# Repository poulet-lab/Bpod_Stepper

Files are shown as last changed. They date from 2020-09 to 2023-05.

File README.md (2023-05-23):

# Bpod Stepper Module

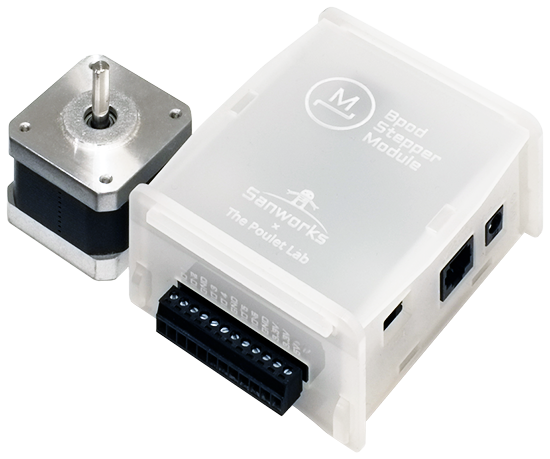
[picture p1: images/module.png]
The *Bpod Stepper Module* enables virtually noiseless operation of a stepper motor by combining smooth acceleration profiles with a *SilentStepStick* driver. You can use it either as a module for *Bpod state machine r2* or as a stand-alone USB device.

## Wiki

Please refer to [**the wiki**](../../wiki) for documentation.

## Credits ##

* Concept & firmware by Florian Rau and Josh Sanders
* PCB layout by Christopher Schultz, Josh Sanders and Florian Rau
* PCB layout partially based on:
  * [Bpod Teensy Shield](https://github.com/sanworks/Bpod-CAD/tree/master/PCB/Modules/Gen2/Bpod%20Teensy%20Shield) by Sanworks ([GPL v3](https://www.gnu.org/licenses/gpl-3.0.en.html))
  * [SilentStepStick Protector](https://github.com/watterott/SilentStepStick) by Watterott ([CC BY-SA 4.0](https://creativecommons.org/licenses/by-sa/4.0/))
* Library dependencies:
  * [ArCOM](https://github.com/bimac/ArCOM) by Sanworks ([GPL v3](https://www.gnu.org/licenses/gpl-3.0.en.html))
  * [TeensyStep](https://github.com/luni64/TeensyStep) by luni64 ([MIT](https://opensource.org/licenses/MIT))
  * [TMCStepper](https://github.com/teemuatlut/TMCStepper) by teemuatlut ([MIT](https://opensource.org/licenses/MIT))
  * [Teensy3x_QuadDecode](https://github.com/bimac/Teensy3x_QuadDecode.git) by TLB ([MIT](https://opensource.org/licenses/MIT))

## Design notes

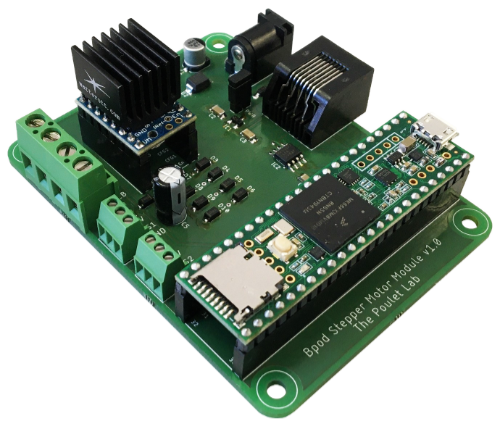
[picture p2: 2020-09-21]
images/board.png

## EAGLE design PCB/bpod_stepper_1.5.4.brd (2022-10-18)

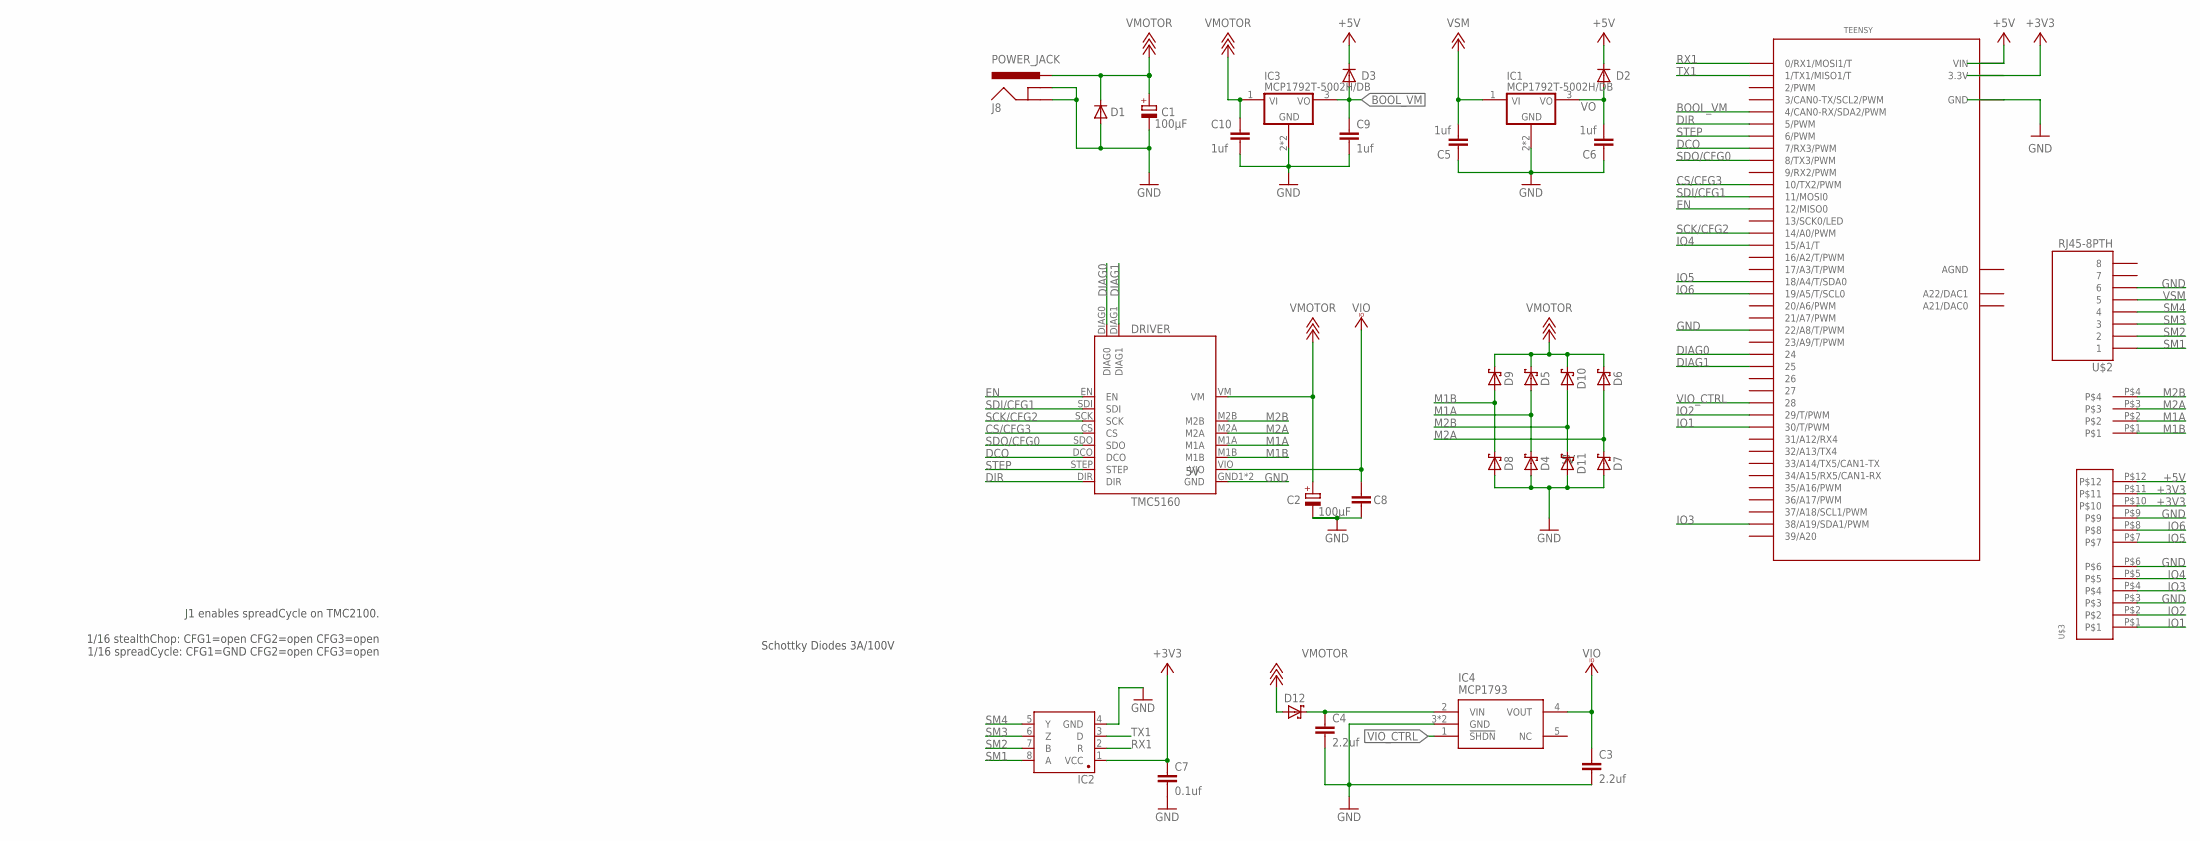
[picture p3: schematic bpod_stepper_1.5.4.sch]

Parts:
C1, C2: 100µF; PANASONIC_G
C3, C4: 2.2uf; 1206@1
C5, C6, C9, C10: 1uf; 1206@1
C7: 0.1uf; 1206@1
C8: 100nf; 1206@1
D1: DIODE-DO214AA; DO214AA
D2, D3: MBR0520LT; SOD123
D4, D5, D6, D7, D8, D9, D10, D11, D12: S310FA; SOD123
DRIVER: TMC5160
IC1, IC3: MCP1792T-5002H/DB; SOT223
IC2: SN65HVD31DR; SO08
IC4: MCP1793; SOT223-5
J8: POWER_JACK; POWER_JACK_PTH
TEENSY: TEENSY_3.6_DIL
U$2: RJ45-8PTH; RJ45-8
U$3: 12POS_MOLEX_SOCKET
U$4: MOLEX395221004

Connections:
+3V3: C7.1, IC2.1 (VCC), TEENSY.3.3V, TEENSY.3.3V3 (3.3V), U$3.P$10, U$3.P$11
+5V: D2.C, D3.C, TEENSY.VIN, U$3.P$12
AGND: TEENSY.AGND
BOOL_VM: C9.1, D3.A, IC3.3 (VO), TEENSY.4 (4/CAN0-RX/SDA2/PWM)
CS/CFG3: DRIVER.CS, TEENSY.10 (10/TX2/PWM)
DCO: DRIVER.DCO, TEENSY.7 (7/RX3/PWM)
DIAG0: DRIVER.DIAG0, TEENSY.24
DIAG1: DRIVER.DIAG1, TEENSY.25
DIR: DRIVER.DIR, TEENSY.5 (5/PWM)
EN: DRIVER.EN, TEENSY.12 (12/MISO0)
GND: C1.-, C2.-, C3.2, C4.2, C5.1, C6.1, C7.2, C8.2, C9.2, C10.2, D1.A, D4.A, D7.A, D8.A, D11.A, DRIVER.GND1 (GND), DRIVER.GND2 (GND), IC1.2 (GND), IC1.4 (GND), IC2.4 (GND), IC3.2 (GND), IC3.4 (GND), IC4.3 (GND), IC4.6 (GND), J8.GND, J8.GNDBREAK, TEENSY.22/A8 (22/A8/T/PWM), TEENSY.GND, TEENSY.GND1 (GND), U$2.6, U$3.P$3, U$3.P$6, U$3.P$9
IO1: TEENSY.30 (30/T/PWM), U$3.P$1
IO2: TEENSY.29 (29/T/PWM), U$3.P$2
IO3: TEENSY.38/A19 (38/A19/SDA1/PWM), U$3.P$4
IO4: TEENSY.15/A1 (15/A1/T), U$3.P$5
IO5: TEENSY.18/A4 (18/A4/T/SDA0), U$3.P$7
IO6: TEENSY.19/A5 (19/A5/T/SCL0), U$3.P$8
M1A: D4.C, D5.A, DRIVER.M1A, U$4.P$2
M1B: D8.C, D9.A, DRIVER.M1B, U$4.P$1
M2A: D6.A, D7.C, DRIVER.M2A, U$4.P$3
M2B: D10.A, D11.C, DRIVER.M2B, U$4.P$4
unnamed: C4.1, D12.C, IC4.2 (VIN)
RX1: IC2.2 (R), TEENSY.0 (0/RX1/MOSI1/T)
SCK/CFG2: DRIVER.SCK, TEENSY.14/A0 (14/A0/PWM)
SDI/CFG1: DRIVER.SDI, TEENSY.11 (11/MOSI0)
SDO/CFG0: DRIVER.SDO, TEENSY.8 (8/TX3/PWM)
SM1: IC2.8 (A), U$2.1
SM2: IC2.7 (B), U$2.2
SM3: IC2.6 (Z), U$2.3
SM4: IC2.5 (Y), U$2.4
STEP: DRIVER.STEP, TEENSY.6 (6/PWM)
TX1: IC2.3 (D), TEENSY.1 (1/TX1/MISO1/T)
VIO: C3.1, C8.1, DRIVER.VIO, IC4.4 (VOUT)
VIO_CTRL: IC4.1 (!SHDN), TEENSY.28
VMOTOR: C1.+, C2.+, C10.1, D1.C, D5.C, D6.C, D9.C, D10.C, D12.A, DRIVER.VM, IC3.1 (VI), J8.PWR
VO: C6.2, D2.A, IC1.3 (VO)
VSM: C5.2, IC1.1 (VI), U$2.5

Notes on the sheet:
Schottky Diodes 3A/100V
J1 enables spreadCycle on TMC2100. 1/16 stealthChop: CFG1=open CFG2=open CFG3=open 1/16 spreadCycle: CFG1=GND CFG2=open CFG3=open

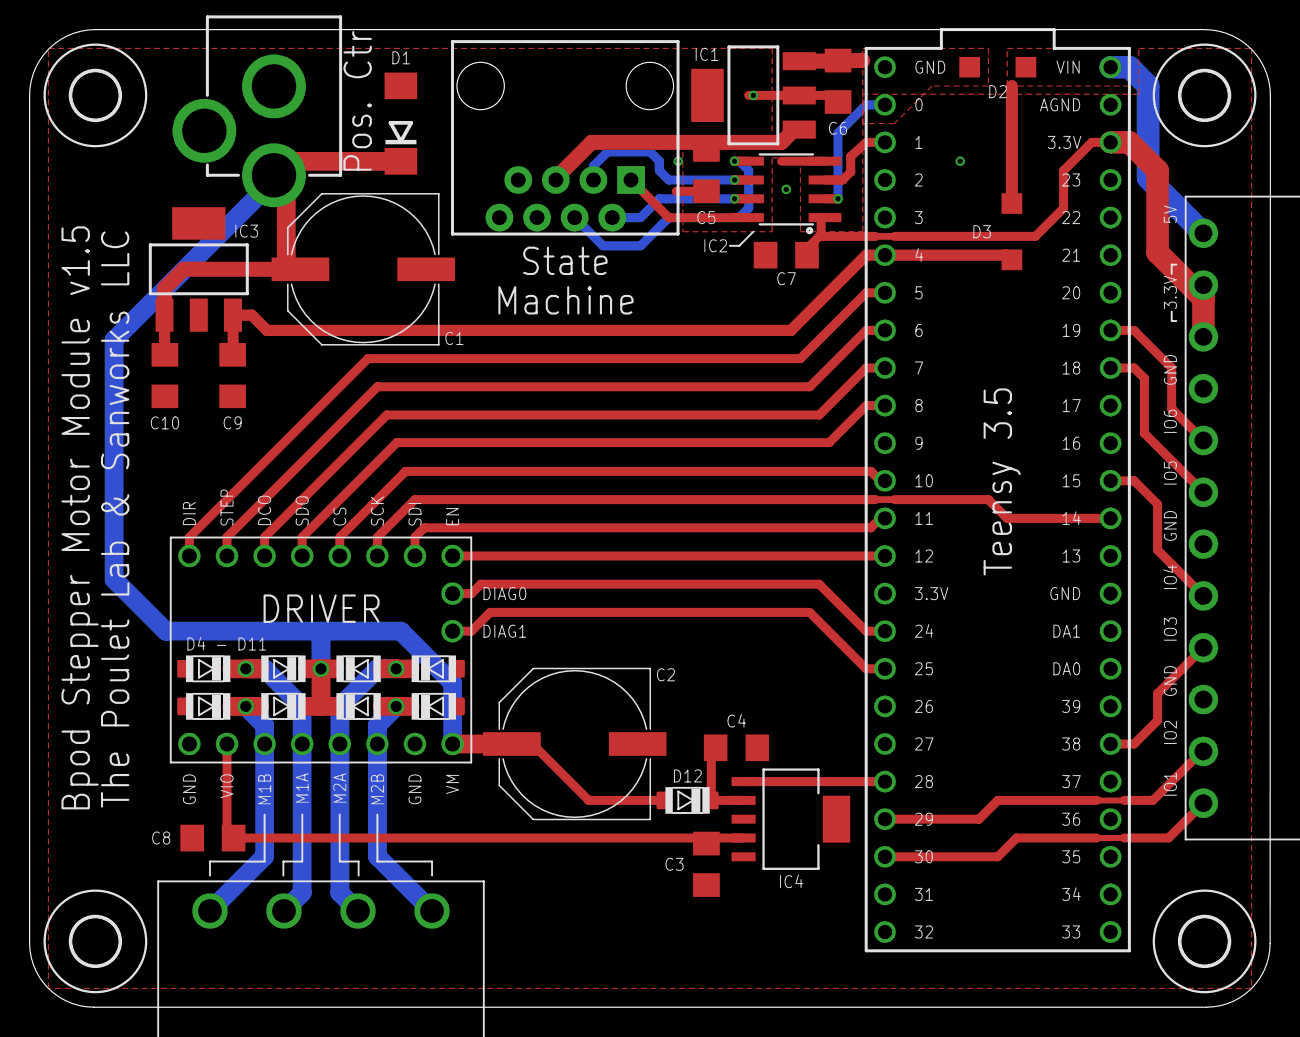
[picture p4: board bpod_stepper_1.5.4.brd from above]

Board: 2 copper layers, 83.8 x 66.0 mm, 36 parts (0 on the bottom side), 36 nets.

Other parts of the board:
U$7, U$8, U$9, U$10: 3,2

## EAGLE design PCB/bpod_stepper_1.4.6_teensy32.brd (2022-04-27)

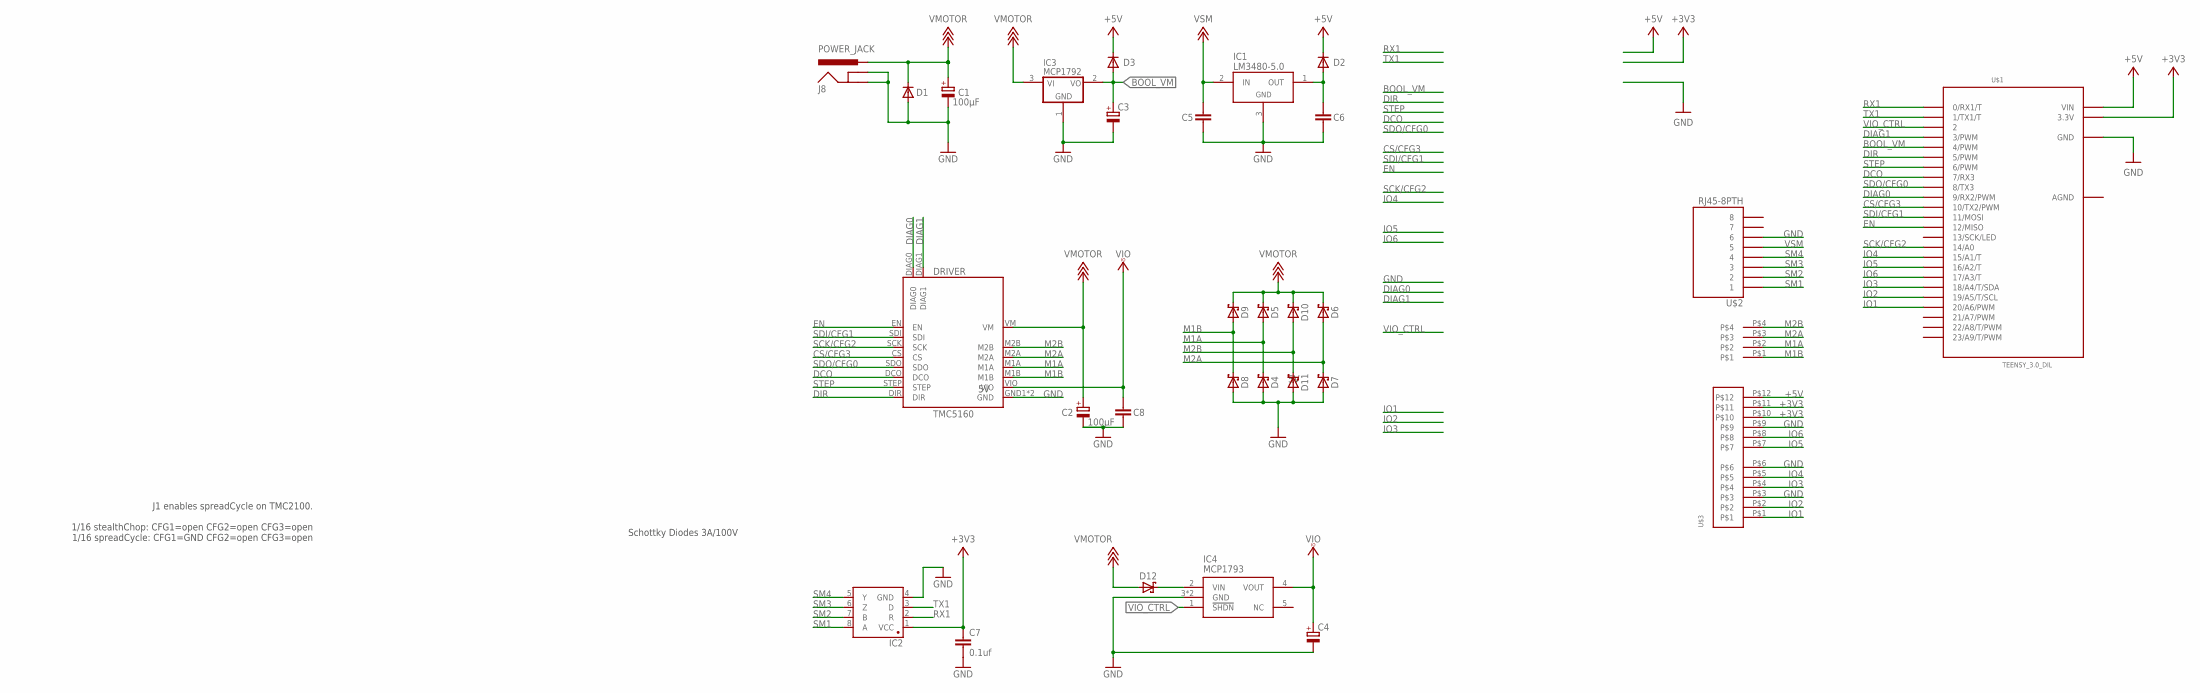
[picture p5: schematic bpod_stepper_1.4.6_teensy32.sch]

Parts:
C1, C2: 100µF; PANASONIC_G
C3, C4: CPOL-EUB; PANASONIC_B
C5, C6, C7: 0.1uf; 1206@1
C8: 100nf; 1206@1
D1: DIODE-DO214AA; DO214AA
D2, D3: MBR0520LT; SOD123
D4, D5, D6, D7, D8, D9, D10, D11, D12: S310FA; SOD123
DRIVER: TMC5160
IC1: LM3480-5.0; SOT-23-3
IC2: SN65HVD31DR; SO08
IC3: MCP1792; SOT23A_MICROCHIP_CB
IC4: MCP1793; SOT223-5
J8: POWER_JACK; POWER_JACK_PTH
U$1: TEENSY_3.0_DIL; TEENSY_3.0-3.2&LC_DIL
U$2: RJ45-8PTH; RJ45-8
U$3: 12POS_MOLEX_SOCKET
U$4: MOLEX395221004

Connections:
+3V3: C7.1, IC2.1 (VCC), U$1.3.3V, U$3.P$10, U$3.P$11
+5V: D2.C, D3.C, U$1.VIN, U$3.P$12
AGND: U$1.AGND
BOOL_VM: C3.+, D3.A, IC3.2 (VO), U$1.4 (4/PWM)
CS/CFG3: DRIVER.CS, U$1.10 (10/TX2/PWM)
DCO: DRIVER.DCO, U$1.7 (7/RX3)
DIAG0: DRIVER.DIAG0, U$1.9 (9/RX2/PWM)
DIAG1: DRIVER.DIAG1, U$1.3 (3/PWM)
DIR: DRIVER.DIR, U$1.5 (5/PWM)
EN: DRIVER.EN, U$1.12 (12/MISO)
GND: C1.-, C2.-, C3.-, C4.-, C5.1, C6.1, C7.2, C8.2, D1.A, D4.A, D7.A, D8.A, D11.A, DRIVER.GND1 (GND), DRIVER.GND2 (GND), IC1.3 (GND), IC2.4 (GND), IC3.1 (GND), IC4.3 (GND), IC4.6 (GND), J8.GND, J8.GNDBREAK, U$1.GND, U$2.6, U$3.P$3, U$3.P$6, U$3.P$9
IO1: U$1.20/A6 (20/A6/PWM), U$3.P$1
IO2: U$1.19/A5 (19/A5/T/SCL), U$3.P$2
IO3: U$1.18/A4 (18/A4/T/SDA), U$3.P$4
IO4: U$1.15/A1 (15/A1/T), U$3.P$5
IO5: U$1.16/A2 (16/A2/T), U$3.P$7
IO6: U$1.17/A3 (17/A3/T), U$3.P$8
M1A: D4.C, D5.A, DRIVER.M1A, U$4.P$2
M1B: D8.C, D9.A, DRIVER.M1B, U$4.P$1
M2A: D6.A, D7.C, DRIVER.M2A, U$4.P$3
M2B: D10.A, D11.C, DRIVER.M2B, U$4.P$4
unnamed: D12.C, IC4.2 (VIN)
unnamed: C6.2, D2.A, IC1.1 (OUT)
RX1: IC2.2 (R), U$1.0 (0/RX1/T)
SCK/CFG2: DRIVER.SCK, U$1.14/A0
SDI/CFG1: DRIVER.SDI, U$1.11 (11/MOSI)
SDO/CFG0: DRIVER.SDO, U$1.8 (8/TX3)
SM1: IC2.8 (A), U$2.1
SM2: IC2.7 (B), U$2.2
SM3: IC2.6 (Z), U$2.3
SM4: IC2.5 (Y), U$2.4
STEP: DRIVER.STEP, U$1.6 (6/PWM)
TX1: IC2.3 (D), U$1.1 (1/TX1/T)
VIO: C4.+, C8.1, DRIVER.VIO, IC4.4 (VOUT)
VIO_CTRL: IC4.1 (!SHDN), U$1.2
VMOTOR: C1.+, C2.+, D1.C, D5.C, D6.C, D9.C, D10.C, D12.A, DRIVER.VM, IC3.3 (VI), J8.PWR
VSM: C5.2, IC1.2 (IN), U$2.5

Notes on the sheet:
Schottky Diodes 3A/100V
J1 enables spreadCycle on TMC2100. 1/16 stealthChop: CFG1=open CFG2=open CFG3=open 1/16 spreadCycle: CFG1=GND CFG2=open CFG3=open

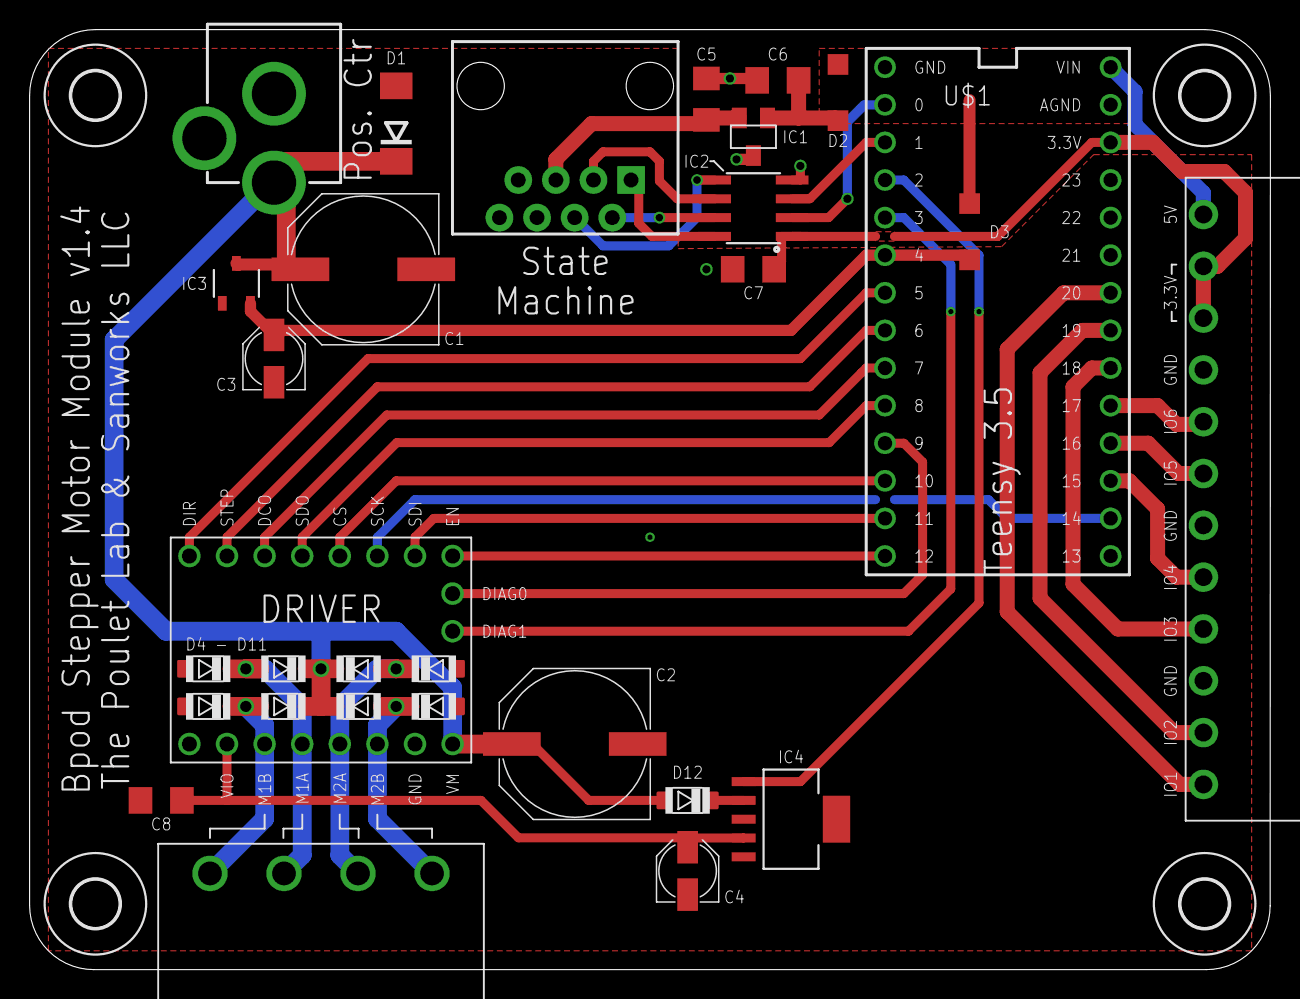
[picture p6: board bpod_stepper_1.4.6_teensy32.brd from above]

Board: 2 copper layers, 83.8 x 63.5 mm, 34 parts (0 on the bottom side), 36 nets.

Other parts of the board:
U$7, U$8, U$9, U$10: 3,2

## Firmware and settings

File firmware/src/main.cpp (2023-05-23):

/*
Bpod_stepper
Copyright (C) 2023 Florian Rau

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
You should have received a copy of the GNU General Public License along with
this program.  If not, see <http://www.gnu.org/licenses/>.
*/

#include "EEstore.h"       // Import EEstore library
#include "EEstoreStruct.h" // Parameters to be loaded from EEPROM (and default values)
#include "SerialDebug.h"    // Some debugging tools
#include "StepperWrapper.h" // Wrap stepper motor control
#include <ArCOM.h>          // Import serial communication wrapper
#include <Arduino.h>

void returnModuleInfo();

// Serial communication
ArCOM usbCOM(Serial);      // Wrap Serial (USB on Teensy 3.X)
ArCOM Serial1COM(Serial1); // Wrap Serial1 (UART on Teensy 3.X)
ArCOM *COM;                // Pointer to ArCOM object

// Variables
uint8_t opCode = 0;      // opCode for loop()
storageVars p;           // struct for EEPROM storage (see EEstoreStruct.h)
StepperWrapper *stepper; // Pointer to StepperWrapper

void setup()
{
  // Initialize serial communication
  Serial1.begin(1312500);

  // Load parameters from EEPROM
  EEstore<storageVars>::getOrDefault(p);

  // Decide which implementation of StepperWrapper to use
  if (!StepperWrapper::SDmode())
    stepper = new StepperWrapper_MotionControl();
  else
    stepper = new StepperWrapper_TeensyStep();

  // Initialize StepperWrapper
  stepper->init();
}


void loop()
{
  if (ISRcode>0) {                                                // Byte set through interrupt sub-routine
    opCode  = ISRcode;
    ISRcode = 0;
  }
  else {
    if (usbCOM.available()>0)                                     // Byte available at usbCOM?
      COM = &usbCOM;                                              //   Point *COM to usbCOM
    else if (Serial1COM.available())                              // Byte available at Serial1COM?
      COM = &Serial1COM;                                          //   Point *COM to Serial1COM
    else                                                          // Otherwise
      return;                                                     //   Skip to next iteration of loop()
    opCode = COM->readByte();
  }

  if (opCode <= 9 && opCode >= 1)  {                              // Move to predefined target (0-9)
    stepper->go2target(opCode-1);
    return;
  }
  switch(opCode) {
    case 'X':                                                     // Stop without slowing down
      stepper->hardStop();
      return;
    case 'x':                                                     // Stop after slowing down
      stepper->softStop();
      return;
    case 'S':                                                     // Move to relative position, full steps (pos = CW, neg = CCW)
      stepper->vMax(p.vMax);
      stepper->a(p.a);
      stepper->moveSteps(COM->readInt16());
      return;
    case 's':                                                     // Move to relative position, micro-steps (pos = CW, neg = CCW)
      stepper->vMax(p.vMax);
      stepper->a(p.a);
      stepper->moveMicroSteps(COM->readInt32());
      return;
    case 'P':                                                     // Move to absolute position, full steps
      stepper->vMax(p.vMax);
      stepper->a(p.a);
      stepper->position(COM->readInt16());
      return;
    case 'p':                                                     // Move to absolute position, micro-steps
      stepper->vMax(p.vMax);
      stepper->a(p.a);
      stepper->microPosition(COM->readInt32());
      return;
    case 'F':                                                     // Start moving forwards
      stepper->vMax(p.vMax);
      stepper->a(p.a);
      stepper->rotate(1);
      return;
    case 'B':                                                     // Start moving backwards
      stepper->vMax(p.vMax);
      stepper->a(p.a);
      stepper->rotate(-1);
      return;
    case 'Z':                                                     // Reset position to zero
      stepper->setPosition(0);
      return;
    case 'z':                                                     // Reset encoder position to zero
      stepper->resetEncoderPosition();
      return;
    case 'A':                                                     // Set acceleration (steps / s^2)
      stepper->a(COM->readUint16());
      p.a = stepper->a();
      return;
    case 'V':                                                     // Set peak velocity (steps / s)
      stepper->vMax(COM->readUint16());
      p.vMax = stepper->vMax();
      return;
    case 'I':                                                     // Set RMS current (mA)
      stepper->RMS(COM->readUint16());
      p.rms_current = stepper->RMS();
      return;
    case 'i':                                                     // Set hold RMS current (mA)
      stepper->holdRMS(COM->readUint16());
      p.hold_rms_current = stepper->holdRMS();
      return;
    case 'C':                                                     // Set chopper mode (0 = PWM chopper, 1 = voltage chopper, 2 = constant off time)
      stepper->setChopper(COM->readUint8());
      p.chopper = stepper->getChopper();
      return;
    case 'M':                                                     // Set mode for IO port
    {
      uint8_t idx  = COM->readUint8();
      uint8_t mode = COM->readUint8();
      stepper->setIOmode(idx,mode);
      if (idx>0 && idx <= 6)
        p.IOmode[idx-1] = stepper->getIOmode(idx);
      return;
    }
    case 'R':                                                     // Set input resistor for IO port (0 = no resistor, 1 = pullup, 2 = pulldown)
    {
      uint8_t idx = COM->readUint8();
      uint8_t res = COM->readUint8();
      stepper->setIOresistor(idx,res);
      if (idx>0 && idx <= 6)
        p.IOresistor[idx-1] = stepper->getIOresistor(idx);
      return;
    }
    case 'Y':                                                     // Set steps per revolution
    {
      stepper->stepsPerRevolution(COM->readUint16());
      p.stepsPerRevolution = stepper->stepsPerRevolution();
      return;
    }
    case 'y':                                                     // Set encoder steps per revolution
    {
      stepper->countsPerRevolution(COM->readUint16());
      p.countsPerRevolution = stepper->countsPerRevolution();
      return;
    }
    case 'T':                                                     // Set predefined target
    {
      uint8_t idx = COM->readUint8() - 1;
      if (idx <= 8 && idx >= 0) {
        p.target[idx]       = COM->readInt32();                   //   target position
        p.aTarget[idx]      = COM->readUint16();                  //   acceleration
        p.vMaxTarget[idx]   = COM->readUint16();                  //   speed
        p.relTargetPos[idx] = COM->readUint8() > 0;               //   absolute / relative target
      }
      return;
    }
    case 'E':                                                     // Store current settings to EEPROM
      EEstore<storageVars>::set(p);
      return;
    case 'L':                                                     // Toggle live streaming of motor status
    {
      bool enable = COM->readUint8();
      stepper->setStream(enable);
      return;
    }
  }

  // The following commands will also RETURN data via serial - they cannot be used during stream mode
  if (COM == &usbCOM && stepper->getStream())
    return;
  switch(opCode) {
    case 'G':                                                     // Get parameters
      opCode = COM->readByte();                                   //   Read Byte
      if (opCode <= 9 && opCode >= 1) {                           //   Return predefined target
        uint8_t idx = opCode - 1;
        COM->writeInt32(p.target[idx]);
        COM->writeUint16(round(p.aTarget[idx]));
        COM->writeUint16(round(p.vMaxTarget[idx]));
        COM->writeUint8(p.relTargetPos[idx]);
        return;
      }
      switch (opCode) {
        case 'P':                                                 //   Return position
          COM->writeInt16(stepper->position());
          break;
        case 'p':                                                 //   Return micro-position
          COM->writeInt32(stepper->microPosition());
          break;
        case 'N':                                                 //   Return encoder position
          COM->writeInt32(stepper->encoderPosition());
          break;
        case 'A':                                                 //   Return acceleration
          COM->writeUint16(round(stepper->a()));
          break;
        case 'V':                                                 //   Return speed
          COM->writeUint16(round(stepper->vMax()));
          break;
        case 'H':                                                 //   Return hardware revision
          COM->writeUint8(stepper->PCBrev);
          break;
        case 'M':
          COM->writeUint8(stepper->getIOmode(COM->readByte()));
          break;
        case 'R':
          COM->writeUint8(stepper->getIOresistor(COM->readByte()));
          break;
        case 'I':
          COM->writeUint16(stepper->RMS());
          break;
        case 'i':
          COM->writeUint16(stepper->holdRMS());
          break;
        case 'C':                                                 //   Return chopper mode (0 = PWM chopper, 1 = voltage chopper, 2 = constant off time)
          COM->writeUint8(stepper->getChopper());
          break;
        case 'T':
          COM->writeUint8(stepper->vDriver);
          break;
        case 'Y':                                                 //   Return steps per revolution
          COM->writeUint16(stepper->stepsPerRevolution());
          break;
        case 'y':                                                 //   Return encoder counts per revolution
          COM->writeUint16(stepper->countsPerRevolution());
          break;

      }
      break;
    case 212:                                                     // USB Handshake
      if (COM == &usbCOM) {                                       //   Check if connected via USB
        COM->writeByte(211);
        COM->writeUint32(FIRMWARE_VERSION);
      }
      break;
    case 255:                                                     // Return module information
      if (COM == &Serial1COM) {                                   //   Check if connected via UART
        returnModuleInfo();
      }
      break;
  }
}

void returnModuleInfo() {
  char  moduleName[] = "Stepper";
  const char* eventNames[] = {"Error", "Start", "Stop", "EStop"};
  uint8_t nEventNames  = sizeof(eventNames) / sizeof(char *);

  // FSM firmware v23 or newer sends a second info request byte to indicate that
  // it supports additional ops
  delayMicroseconds(100);
  boolean fsmSupportsHwInfo =
    (Serial1COM.available() && Serial1COM.readByte() == 255) ? true : false;

  Serial1COM.writeByte(65);                                       // Acknowledge
  Serial1COM.writeUint32(FIRMWARE_VERSION);                       // 4-byte firmware version
  Serial1COM.writeByte(sizeof(moduleName) - 1);
  Serial1COM.writeCharArray(moduleName, sizeof(moduleName) - 1);  // Module name
  Serial1COM.writeByte(1);                                        // 1 if more info follows, 0 if not
  Serial1COM.writeByte('#');                                      // Op code for: Number of behavior events this module can generate
  Serial1COM.writeByte(nEventNames);
  Serial1COM.writeByte(1);                                        // 1 if more info follows, 0 if not
  Serial1COM.writeByte('E');                                      // Op code for: Behavior event names
  Serial1COM.writeByte(nEventNames);
  for (unsigned int i = 0; i < nEventNames; i++) {                // Once for each event name
    Serial1COM.writeByte(strlen(eventNames[i]));                  // Send event name length
    for (unsigned int j = 0; j < strlen(eventNames[i]); j++) {    // Once for each character in this event name
      Serial1COM.writeByte(*(eventNames[i] + j));                 // Send the character
    }
  }
  if (fsmSupportsHwInfo) {
    Serial1COM.writeByte(1);                                      // 1 if more info follows, 0 if not
    Serial1COM.writeByte('V');                                    // Op code for: Hardware major version
    Serial1COM.writeByte(stepper->PCBrev/10);
    Serial1COM.writeByte(1);                                      // 1 if more info follows, 0 if not
    Serial1COM.writeByte('v');                                    // Op code for: Hardware minor version
    Serial1COM.writeByte(stepper->PCBrev%10);
  }
  Serial1COM.writeByte(0);                                        // 1 if more info follows, 0 if not
}

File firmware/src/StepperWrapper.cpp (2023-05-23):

/*
StepperWrapper
Copyright (C) 2023 Florian Rau

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
You should have received a copy of the GNU General Public License along with
this program.  If not, see <http://www.gnu.org/licenses/>.
*/

#include <ArCOM.h>
#include <Arduino.h>
#include <TMCStepper.h>
#include "SerialDebug.h"
#include "StepperWrapper.h"

// Some macros for later use
#define CHM_CONSTOFFTIME true // constant off-time chopper
#define CHM_SPREADCYCLE false // spreadCycle chopper
#define CHOP_PWM 0            // spreadCycle chopper
#define CHOP_VOLTAGE 1        // stealthChop chopper
#define CHOP_CONSTOFF 2       // constant off-ime chopper

// In order to use identically named methods of different child classes of
// TMCStepper we define lambda functions that are initalized by the following
// pre-processor macro:
#define setLambdas(DRV)                                                        \
  {                                                                            \
  cs2rms            = [](uint8_t CS)   { return DRV->cs2rms(CS); };            \
  sg_result         = []()             { return DRV->sg_result(); };           \
  get_chm           = []()             { return DRV->chm(); };                 \
  set_chm           = [](bool val)     {        DRV->chm(val); };              \
  get_en_pwm_mode   = []()             { return DRV->en_pwm_mode(); };         \
  set_en_pwm_mode   = [](bool val)     {        DRV->en_pwm_mode(val); };      \
  get_freewheel     = []()             { return DRV->freewheel() == 0x01; };   \
  set_freewheel     = [](bool val)     {        DRV->freewheel(val); };        \
  get_ihold         = []()             { return DRV->ihold(); };               \
  set_ihold         = [](uint8_t CS)   {        DRV->ihold(CS); };             \
  get_microsteps    = []()             { return DRV->microsteps(); };          \
  set_microsteps    = [](uint16_t ms)  {        DRV->microsteps(ms); };        \
  get_rms_current   = []()             { return DRV->rms_current(); };         \
  set_rms_current   = [](uint16_t I)   {        DRV->rms_current(I); };        \
  get_sfilt         = []()             { return DRV->sfilt(); };               \
  set_sfilt         = [](bool val)     {        DRV->sfilt(val); };            \
  get_sgt           = []()             { return DRV->sgt(); };                 \
  set_sgt           = [](int8_t val)   {        DRV->sgt(val); };              \
  get_TPWMTHRS      = []()             { return DRV->TPWMTHRS(); };            \
  set_TPWMTHRS      = [](uint32_t val) {        DRV->TPWMTHRS(val); };         \
}

extern ArCOM usbCOM;

namespace {

const uint8_t idPCB() {
  static uint8_t out = 0;
  if (out > 0) {
    return out;
  }

  // r1.4 onwards has the revision number coded in hardware. It can be read by
  // checking if pins 20-23 are connected to GND. The connection status forms a
  // binary code:
  //
  //       pin20 pin21 pin22 pin23
  // r1.4x                     x
  // r1.5x               x
  // r1.6x               x     x
  // r1.7x         x
  // etc.
  for (int i = 23; i >= 20; i--) {
    pinMode(i, INPUT_PULLUP);
    delayMicroseconds(10);
    bitWrite(out, abs(i - 23), !digitalReadFast(i));
    pinMode(i, INPUT_DISABLE);
  }
  if (out) {
    out += 13;
  } else {
    // revisions older than 1.4 can be detected by other means: for r1.2 and
    // r1.3, pin 29 reads HIGH; r1.3 connects pin 9 and 14, r1.2 does not.
    pinMode(29, INPUT);
    if (digitalReadFast(29)) {
      pinMode(9, OUTPUT);
      digitalWriteFast(9, LOW);
      pinMode(14, INPUT_PULLUP);
      delayMicroseconds(10);
      out = (digitalReadFast(14)) ? 12 : 13;
      pinMode(9, INPUT_DISABLE);
      pinMode(14, INPUT_DISABLE);
    } else {
      out = 11; // otherwise its r1.1
    }
    pinMode(29, INPUT_DISABLE);
  }
  return out;
}

const teensyPins getPins() {
  teensyPins pin;
  uint8_t PCBrev = idPCB();
  if (PCBrev <= 11) { // the original layout
    pin.Dir = 2;
    pin.Step = 3;
    pin.Sleep = 4;
    pin.Reset = 5;
    pin.CFG3 = 6;
    pin.CFG2 = 7;
    pin.CFG1 = 8;
    pin.En = 9;
    pin.IO[0] = 10; // IO1 - watch out, zero indexing!
    pin.IO[1] = 11; // IO2
    return pin;
  } else { // r1.2 major reorganization
    pin.Dir = 4;
    pin.Step = 5;
    pin.Sleep = 6;
    pin.Reset = 12;
    pin.CFG3 = 8;
    pin.CFG2 = 27;
    pin.CFG1 = 11;
    pin.En = 24;
    pin.IO[0] = 36; // IO1 - watch out, zero indexing!
    pin.IO[1] = 37; // IO2
    pin.IO[2] = 38; // IO3
    pin.IO[3] = 14; // IO4
    pin.IO[4] = 18; // IO5
    pin.IO[5] = 19; // IO6
  }
  if (PCBrev >= 13) { // r1.3: corrected layout for hardware SPI
    pin.Dir = 5;
    pin.Step = 6;
    pin.Sleep = 7;
    pin.Reset = 8;
    pin.CFG3 = 10;
    pin.CFG2 = 14;
    pin.En = 12;
    pin.IO[3] = 15; // IO4
  }
  if (PCBrev >= 14) { // r1.4: DIAG pins, VIO control and VM monitoring
    pin.Diag0 = 24;
    pin.Diag1 = 25;
    pin.VIO = 28;
    pin.VM = 4;
  }
  if (PCBrev >= 15) { // r1.5: hardware quadrature encoder
    pin.IO[0] = 30;   // IO1 - watch out, zero indexing!
    pin.IO[1] = 29;   // IO2
  }
  return pin;
}

union vFirmware {
  struct {
    uint8_t index;
    uint8_t month;
    uint16_t year;
  };
  uint32_t val = FIRMWARE_VERSION;
};

IntervalTimer timerErrorBlink;
} // namespace

extern ArCOM Serial1COM;
volatile uint8_t errorID = 0;
volatile uint8_t ISRcode = 0;

// initialize static members
const uint8_t StepperWrapper::PCBrev = idPCB();
const teensyPins StepperWrapper::pin = getPins();
TMC2130Stepper *const StepperWrapper::TMC2130(
    StepperWrapper::getDriver<TMC2130Stepper>(0.110, 0x11));
TMC5160Stepper *const StepperWrapper::TMC5160(
    StepperWrapper::getDriver<TMC5160Stepper>(0.075, 0x30));
const uint8_t StepperWrapper::vDriver = StepperWrapper::idDriver();
const bool StepperWrapper::is2130 = (StepperWrapper::vDriver == 0x11);
const bool StepperWrapper::is5160 = (StepperWrapper::vDriver == 0x30);
template <class T>
T *const StepperWrapper::driver = (StepperWrapper::is2130) ? TMC2130 : TMC5160;
const uint32_t StepperWrapper::fCLK = (StepperWrapper::is2130) ? 12.2E6 : 12E6;
const char *StepperWrapper::driverName =
    (StepperWrapper::is2130) ? "TMC2130" : "TMC5160";
const uint8_t StepperWrapper::_nIO = (PCBrev < 12) ? 2 : 6;

StepperWrapper::StepperWrapper() {

  pinMode(pin.En, OUTPUT);
  pinMode(LED_BUILTIN, OUTPUT);

  if (PCBrev >= 14) {
    pinMode(pin.VIO, OUTPUT);
    pinMode(pin.Diag0, INPUT);
    pinMode(pin.Diag1, INPUT);

    // detect presence of motor power supply
    pinMode(pin.VM, INPUT);
    attachInterrupt(digitalPinToInterrupt(pin.VM), ISRchangeVM, CHANGE);
    if (!digitalRead(pin.VM)) {
      throwError(STEPPER_ERROR___VM_UNPLUGGED);
    }
  }

  TimerStream.priority(255); // lowest priority for stream

  enableDriver(false); // disable driver for now
  powerDriver(true);   // power the driver
}
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

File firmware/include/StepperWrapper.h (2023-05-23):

/*
StepperWrapper
Copyright (C) 2023 Florian Rau

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

_______________________________________________________________________________
*/

#pragma once
#include <ArCOM.h>          // https://github.com/bimac/ArCOM
#include <Arduino.h>
#include <QuadDecode_def.h> // https://github.com/bimac/Teensy3x_QuadDecode
#include <SD.h>             // https://github.com/PaulStoffregen/SD
#include <TMCStepper.h>     // https://github.com/teemuatlut/TMCStepper
#include <TeensyStep.h>     // https://github.com/luni64/TeensyStep
#include "EEstoreStruct.h"

#define STEPPER_ERROR___NO_DRIVER_FOUND 1
#define STEPPER_ERROR___VM_UNPLUGGED 2
#define STEPPER_ERROR___UNDER_VOLTAGE 3
#define STEPPER_ERROR___OVER_TEMPERATURE 4
#define STEPPER_ERROR___OVER_TEMPERATURE_PRE 5
#define STEPPER_ERROR___SHORT_TO_GND_PHASE_A 6
#define STEPPER_ERROR___SHORT_TO_GND_PHASE_B 7

struct teensyPins {
  uint8_t Dir;
  uint8_t Step;
  uint8_t Sleep;
  uint8_t Reset;
  uint8_t CFG1;
  uint8_t CFG2;
  uint8_t CFG3;
  uint8_t En;
  uint8_t Diag0;
  uint8_t Diag1;
  uint8_t VIO;
  uint8_t VM;
  uint8_t Error;
  uint8_t IO[6]{0};
};

extern volatile uint8_t errorID; // error ID (set through interrupt sub-routine)
extern volatile uint8_t ISRcode; // opCode (set through interrupt sub-routine)
extern storageVars p;

struct StepperWrapper {
  StepperWrapper(); // constructor

  static TMC2130Stepper *const TMC2130;
  static TMC5160Stepper *const TMC5160;

  static const uint8_t vDriver;              // driver version
  static const uint8_t PCBrev;               // PCB revision
  static const teensyPins pin;               // pin numbers
  static const bool is2130;                  // bool: is TMC2130?
  static const bool is5160;                  // bool: is TMC5160?
  static const uint32_t fCLK;                // internal clock frequency
  static const char *driverName;             // name of motor driver
  template <class T> static T *const driver; // TMCstepper object

  static const uint8_t _nIO;              // number of IO pins
  static constexpr uint16_t _msRes = 256; // micro-stepping resolution

  template <class T>
  static T *getDriver(float, uint8_t); // return pointer to driver (or nullptr)

  virtual void init(); // initialize stepper class

  // templated members
  template <class T> void init(T *);

  virtual void setMicrosteps(uint16_t ms); // set microstepping resolution
  uint16_t getMicrosteps();                // get microstepping resolution

  static void blinkenlights(); // extra fancy LED sequence to say hi
  static uint8_t idDriver();   // identify TMC stepper driver
  static bool SDmode();        // are we using STEP/DIR mode?

  void SGautoTune();

  virtual float a() = 0;       // get acceleration (full steps / s^2)
  virtual void a(float a) = 0; // set acceleration (full steps / s^2)
  virtual void softStop() = 0; // stop after defined slow-down
  virtual void hardStop() = 0; // stop as fast as possible (risk of step-loss)
  virtual void
  moveMicroSteps(int32_t steps) = 0; // move to relative position (micro-steps)
  virtual bool isRunning() = 0;      // is the motor currently running?
  virtual int32_t microPosition() = 0; // get current position (micro-steps)
  virtual void
  microPosition(int32_t target) = 0; // go to absolute position (micro-steps)
  virtual void
  setPosition(int32_t pos) = 0; // set position without moving (microsteps)
  virtual void rotate(int8_t direction) = 0; // initiate rotation
  virtual float vMax() = 0;       // get peak velocity (full steps / s)
  virtual void vMax(float v) = 0; // set peak velocity (full steps / s)

  void rotate();                    // start rotation
  void moveSteps(int32_t steps);    // move to relative position (full-steps)
  void go2target(uint8_t id);       // move to predefined target
  void position(int32_t target);    // move to absolute position (full-steps)
  int32_t position();               // get absolute position (full-steps)
  uint16_t RMS();                   // get RMS current
  void RMS(uint16_t rms_current);   // set RMS current
  void holdRMS(uint16_t val);       // set hold current
  uint16_t holdRMS();               // get hold current
  void setChopper(uint8_t chopper); // set chopper mode
  uint8_t getChopper();             // get chopper mode
  void setIOmode(uint8_t mode[6], uint8_t l); // set IO mode (all IO ports)
  void setIOmode(uint8_t idx, uint8_t role);  // set IO mode (specific IO port)
  uint8_t getIOmode(uint8_t idx);             // get IO mode (specific IO port)
  void setIOresistor(uint8_t r[6],
                     uint8_t l);      // set input resistor (all IO ports)
  void setIOresistor(uint8_t idx,
                     uint8_t r);      // set input resistor (specific IO port)
  uint8_t getIOresistor(uint8_t idx); // get input resistor (specific IO port)
  void setStream(bool enable);        // enable/disable live streaming
  bool getStream();                   // get status of live stream
  int32_t readPosition();             // read _microPosition from SD card
  int32_t encoderPosition();          // get encoder position
  void resetEncoderPosition();        // reset encoder position to zero
  void stepsPerRevolution(uint16_t steps);  // set steps per revolution
  uint16_t stepsPerRevolution();            // get steps per revolution
  void countsPerRevolution(uint16_t steps); // set encoder counts per revolution
  uint16_t countsPerRevolution();           // get encoder counts per revolution

protected:
  static void powerDriver(bool);   // supply VIO to driver board?
  static void enableDriver(bool);  // enable driver board via EN pin?
  static void throwError(uint8_t); // throw error with specified numeric ID
  static void clearError();        // clear error condition

  volatile int32_t _microPosition;

  ArCOM *_COM;
  void toggleISRlimit(int8_t direction);
  bool atLimit(int8_t direction);
  uint16_t _microsteps = 1;
  uint16_t _microstepDiv = 256;
  uint16_t _stepsPerRevolution = 200;
  uint16_t _countsPerRevolution = 32768;
  static constexpr bool _invertPinEn = true;
  bool _invertPinDir = false;
  bool writePosition(int32_t pos); // Write _microPosition to SD card
  uint32_t speed2ticks(float stepsPerSec);
  float ticks2speed(uint32_t ticks);
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

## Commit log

2020-08-25 Add PCB designs
    [bpod_stepper_v1_0.brd, bpod_stepper_v1_0.sch]
2020-09-07 Update README.md
    Switched DC barrel jack for higher voltage rating
2020-09-28 add enclosure designs
2020-09-28 rename eagle files
    [bpod_stepper_1.0.brd, bpod_stepper_1.0.sch]
2020-09-28 moved board.png
2020-09-28 update enclosure designs
2020-09-30 add inversion option for direction pin
2020-10-01 add routine for limit switches
2020-10-01 add option for inverted limit switches
    [Bpod_stepper.ino]
2020-10-05 Update PCB & enclosure to v1.1
    - enlarged capacitors for Vmotor
    - removed 5V lines
    [bpod_stepper_1.1.brd, bpod_stepper_1.1.sch]
2020-10-05 update enclosure design
2020-11-04 -Fixed bug in BpodStepperModule limit switch function definition
2020-11-05 corrected wrong routing for RX & TX
    [bpod_stepper_1.1.brd, bpod_stepper_1.1.sch]
2020-11-12 attach interrupt to limit switches
2020-11-12 Revert "attach interrupt to limit switches"
    This reverts commit 943bb127581417d88d153e89072d6d6259129414.
    [Bpod_stepper.ino]
2020-11-12 switch to digitalWriteFast
2020-11-12 fire limit switch interrupt according to invertLimit
2020-11-12 keep track of last movement direction
2020-11-14 -Merged changes with 'Feat-Interrupt' branch of Poulet Lab Repository -Added function to configure number of steps per revolution (to firmware and MATLAB class) -Switched op menu in firmware to from 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
2020-11-20 keep track of position
2021-04-24 -Added PCB design r1.2 that adds: 1. GPIO breakout to external screw terminal block, 2. Compatability with data features on TMC5160
    [bpod_stepper_1.2.brd, bpod_stepper_1.2.sch]
2021-04-24 clean-up and minor adjustments
    - corrected board dimensions
    - clean-up
    - resized top ground-plane
    - updates to silkscreen
    [bpod_stepper_1.2.brd]
2021-04-26 -Updates to PCB design: Restricted ground plane from board edges, Restricted top ground plane from Bpod module interface circuitry and added vias to bottom plane, Rerouted UART traces to preserve bot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
    [bpod_stepper_1.2.1.brd, bpod_stepper_1.2.1.sch]
2021-04-26 updated PCB
    - added molex connector (PN 0395221004)
    - further separation of motor and logic lines
    [bpod_stepper_1.2.2.brd, bpod_stepper_1.2.2.sch]
2021-04-26 update enclosure for PCB v1.2
2021-04-26 -Added minor revisions to 1.2.2 from PouletLab/Stepper restoring some features of 1.2.1
    [bpod_stepper_1.2.3.brd, bpod_stepper_1.2.3.sch]
2021-08-18 Update Bpod_stepper.ino
    Update pin definitions for PCB 1.2.3
2021-08-19 PCB r1.3 with some reassigned pins
    - Dir: 5 (previously 4)
    - Step: 6 (previously 5)
    - Sleep: 7 (previously 6)
    - Reset/MISO: 8 (previously 12)
    - CFG3/CS: 10 (previously 8)
    - CFG2/SCK: 14 (via 9, previously 27)
    - En: 12 (previously 24)
    - IO4: 15 (previously 14)
    [bpod_stepper_1.3.brd, bpod_stepper_1.3.sch]
2021-09-14 PCB revisions 1.3.1 and 1.4
    [bpod_stepper_1.3.1.brd, bpod_stepper_1.3.1.sch, bpod_stepper_1.4.brd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]
2021-09-21 use 5V VIO for the stepper driver
    [bpod_stepper_1.4.1.brd, bpod_stepper_1.4.1.sch]
2021-09-27 First draft of StepperWrapper
2021-10-04 clean-up of MATLAB code
    - support for RMS current
    - reorganization of dependent properties
    - some documentation
2021-10-05 work on PCB
    [bpod_stepper_1.4.2.brd, bpod_stepper_1.4.2.sch, bpod_stepper_1.4.3.brd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]
2021-10-08 do not invert VIO pin
    [StepperWrapper.cpp]
2021-10-08 driver VIO from 3.3V regulator
    [bpod_stepper_1.4.4.brd, bpod_stepper_1.4.4.sch]
2021-10-12 PCB 1.4.5 & updated BOM
    [bpod_stepper_1.4.5.brd, bpod_stepper_1.4.5.sch]
2021-10-18 less convoluted mode of determining HW revision
    [bpod_stepper_1.4.6.brd, bpod_stepper_1.4.6.sch]
2021-10-25 target handling: optimize for short-circuit eval / use constrain() on user input
    [Bpod_stepper.ino]
2021-10-25 updated enclosure / fixed SVG size
2021-10-27 correct pin.VIO
2021-11-02 debug flags, work on interrupts & error handling
    [Bpod_stepper.ino, StepperWrapper.cpp, StepperWrapper.h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]
2021-11-04 added D12 to prevent current flowing from pin 28 to pin 4
    [bpod_stepper_1.4.6.brd, bpod_stepper_1.4.6.sch]
2021-11-08 simplify handling of errorPin
    [StepperWrapper.cpp, StepperWrapper.h]
2021-11-08 add D12 to BOM
2021-11-08 some work on error handling
    [StepperWrapper.cpp]
2021-11-13 Updated BOM
2021-11-13 LED during movement
2021-11-22 updated enclosure design
2021-11-23 minor updates to geometry / cut-outs
2021-11-29 implement support for TeensyStep library
2021-11-29 implement limit switches
2021-12-06 IO mode: soft stop / simplification of interrupt logic
2021-12-13 improved logic for limit switches
    - dedicated interrupts for forward and backward movements
    - no start of movement when limit switch active
2022-01-07 correction for setting predefined target position
    [Bpod_stepper.ino]
2022-01-10 forgot breaks in switch statement
2022-01-24 avoid superfluous writes to SD
    [StepperWrapper.cpp]
2022-02-16 Squashed commit of the following:
    commit bb7b450f647cebed25347bc011dd67f2798218c8
    Author: Florian Rau <bimac@users.noreply.github.com>
    Date: Thu Feb 17 00:27:25 2022 +0100
    Fixing massive headache with micro-positioning
    commit acb3d993700eefe6f983e04bd046d38e9035e620
    Author: Florian Rau <bimac@users.noreply.github.com>
    Date: Tue Feb 1 16:50:38 2022 +0100
    work on debug flags & microstepping code
    [Bpod_stepper.ino, StepperWrapper.cpp, StepperWrapper.h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]
2022-02-17 keep a few extra samples to improve the scrolling effect
2022-03-02 add luni64's TeensyStep to credits
2022-03-09 fix bug in positioning
    [StepperWrapper_TeensyStep.cpp]
2022-03-09 discontinuous line if samples were skipped
2022-04-27 layout test for teensy 3.2
    [bpod_stepper_1.4.6_teensy32.brd, bpod_stepper_1.4.6_teensy32.sch]
2022-04-27 add environment for jlink probe
2022-04-27 correct missing initialization for _microsteps
    [StepperWrapper.cpp, StepperWrapper_TeensyStep.cpp]
2022-05-03 add support for quadrature encoder
2022-05-03 switch to QuadDecode library
2022-05-04 only show EncoderPosition property when using an encoder
2022-05-04 yet another correction for buggy (micro-)positioning
    [StepperWrapper_TeensyStep.cpp]
2022-05-11 PCB rev 1.5.0
    - Increased board dimensions
    - Swapped two 5V regulators to MCP1792T-5002H/DB
    - Rerouted IO1 and IO2 for compatibility with hardware quadrature encoder
    - Incremented version number
    [bpod_stepper_1.5.0.brd, bpod_stepper_1.5.0.sch]
2022-05-12 PCB rev 1.5.1
    - routed IO1 and IO2 through pins
    - decreased width of board to its original value
    [bpod_stepper_1.5.1.brd, bpod_stepper_1.5.1.sch]
2022-05-13 PCB rev 1.5.2
    - some corrections to silkscreen
    - alignment of barrel jack
    [bpod_stepper_1.5.2.brd, bpod_stepper_1.5.2.sch]
2022-05-18 correct pin definition for PCB rev 1.5
    [StepperWrapper.cpp]
2022-06-09 PCB r1.5.3
    corrected alignment of I/O ports
    [bpod_stepper_1.5.3.brd, bpod_stepper_1.5.3.sch]
2022-06-09 enclosure for v1.5
2022-06-14 Update to TeensyStep enables debugging with -O0
2022-06-14 change PCBrev from float to uint_8t
2022-06-14 keep track of stepper and encoder resolutions
2022-06-14 Feat/encoder (#4)
    * add support for quadrature encoder
    * switch to QuadDecode library
    * only show EncoderPosition property when using an encoder
    * correction of property display
    * correct pin definition for PCB rev 1.5
    * correction of property display - again
    * enable micro-stepped positioning / reorganize & simplify code
    * Update to TeensyStep enables debugging with -O0
    * change PCBrev from float to uint_8t
    * keep track of stepper and encoder resolutions
    * clean-up
    [StepperWrapper.cpp, StepperWrapper.h, StepperWrapper_MotionControl.cpp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]
2022-06-14 Revert "Merge branch 'master' into feat/encoder"
    This reverts commit 334a59fc887a118c55da8c2e2aefc17528980917, reversing
    changes made to 255d939cb33ea68fce392fd7602fa9700544200a.
    [bpod_stepper_1.5.0.brd, bpod_stepper_1.5.0.sch, bpod_stepper_1.5.1.brd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]
2022-06-14 Revert "Feat/encoder (#4)"
    This reverts commit bba3a4f331cdfc3fe15fbe5685656ed6dab4b752.
    [StepperWrapper.cpp, StepperWrapper.h, StepperWrapper_MotionControl.cpp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]
2022-06-14 Revert "Revert "Merge branch 'master' into feat/encoder""
    This reverts commit e8b787a4a0d770befef3abf9346529d7f2fad731.
    [bpod_stepper_1.5.0.brd, bpod_stepper_1.5.0.sch, bpod_stepper_1.5.1.brd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]
2022-08-30 include new reset() method of HW quadrature encoder
    [StepperWrapper.cpp]
2022-10-12 Update BOM
2022-10-18 PCB revision 1.5.4 (#5)
    * Added PCB version 1.5.4 with the following changes:
    -Removed C3, C4 (electrolytic caps on outputs of IC3, IC4)
    -Added C3, C4 (ceramic 2.2uf caps on IC4 input and output)
    -Added C9, C10 (ceramic 1.1uf caps on IC3 input and output)
    -Updated values of C4, C5 from 0.1uf to 1.0uf for use with MCP1799T-5002H/DB
    [bpod_stepper_1.5.4.brd, bpod_stepper_1.5.4.sch]
2022-11-16 control of hold current
2022-11-22 bug-fix: motor doesn't turn after start-up
    [StepperWrapper_TeensyStep.cpp]
2023-02-17 update enclosure design: motor symbols
2023-02-22 Revert "major clean-up"
    This reverts commit 2ff23546487e158650a096977fca89e92f48b85f.
    [StepperWrapper.cpp, StepperWrapper.h, StepperWrapper_TeensyStep.cpp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]
2023-04-12 Revert "Revert "major clean-up""
    This reverts commit fb0b465d4f71cd8352c45875c9491a14c25e1c2b.
    [StepperWrapper.cpp, StepperWrapper.h, StepperWrapper_TeensyStep.cpp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]
2023-05-23 Minor Fixes
    - remove SmoothStepper dependency
    - formatting & typos
    - issue with private copy of storageVars
    [StepperWrapper.h]
2023-05-23 increase default PWM frequency
2023-05-23 update MATLAB class
    - improved legibility of object properties
    - switch to higher precision positioning
    - formatting

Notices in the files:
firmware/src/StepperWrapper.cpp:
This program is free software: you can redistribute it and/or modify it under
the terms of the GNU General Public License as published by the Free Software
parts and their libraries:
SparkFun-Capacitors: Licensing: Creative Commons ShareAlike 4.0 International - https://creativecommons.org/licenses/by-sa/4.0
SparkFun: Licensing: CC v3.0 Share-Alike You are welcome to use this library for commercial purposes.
